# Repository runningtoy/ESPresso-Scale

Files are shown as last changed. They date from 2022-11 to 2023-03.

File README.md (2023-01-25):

 **ESPresso Scale**  
Fully open source (s/w & h/w) scale project.

**Fork of the great project of jousis9** [https://github.com/jousis9/ESPresso-Scale]  
Main work is done by him! Thanks

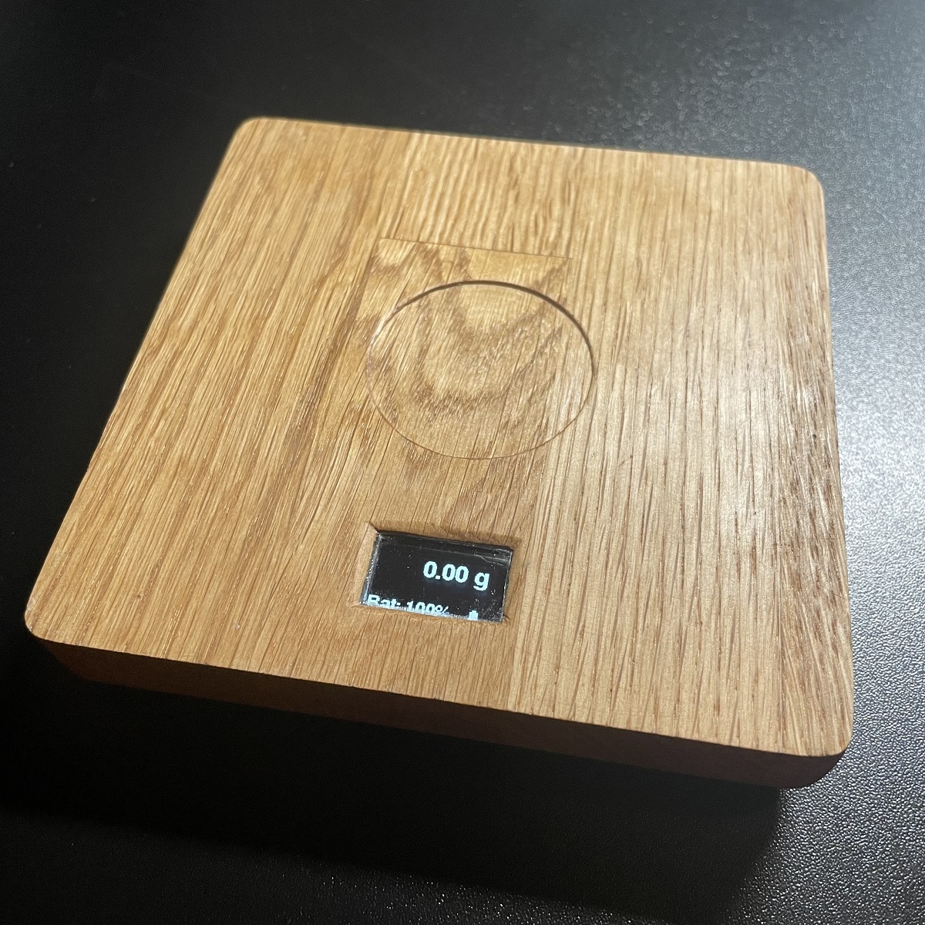
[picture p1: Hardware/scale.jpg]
Scale
  

**Features**
- Open source firmware, software and hardware
- ESP32 (wroom module) MCU
- ADS1232 24-bit ADC from TI
- Lipo and USB powered (I connected a wireless charging pad)
- 10SPS and 80SPS sampling speed with various options regarding filtering/smoothing
- Auto calibration function (selectable weight)
- Touch buttons , using ESP32 pins or external touch module (TTP223).
- 3d printed case (fusion360 files provided)
- Auto power off and consumes no power when "sleep" to extend battery life
- enable WiFi on demand (press both buttons during startup ) -> ```credentials.h```
- OTA support (if WiFi enabled) -> ```http://SCALEIP/update```
- UDP Logging (if WiFi enabled) to ```UDP_SERVER_IP```

**What is provided ?**
- [PCB assembly guide](./Hardware/Documents)
- [Schematics (PDF)](./Hardware/Schematics)
- [PCB easyEDA project export](./Hardware/easyEDA)
- [Fusion 360 project file for the cases](./Hardware/case)
- [Bill of materials (BOM)](./Hardware/Documents) *wip*
- [Firmware (Platform.io IDE project)](./Software/Firmware)

**Documentation**  
*UDP LOGGING Bash*  
Command for UDP Logging  
```bash
nc -u -l -p 44444
```  

**Load Cell**  
- [x] [Mavin NA1](https://www.mavin.cn/na1-oiml-c3-approved-load-cell-high-accuracy-single-point-sensor_p15.html) and 
- [x] [Mavin MV-NA27-2KG](https://www.mavin.cn/kitchen-scale-load-cell-low-capacity-weight-sensor-na27_p28.html)
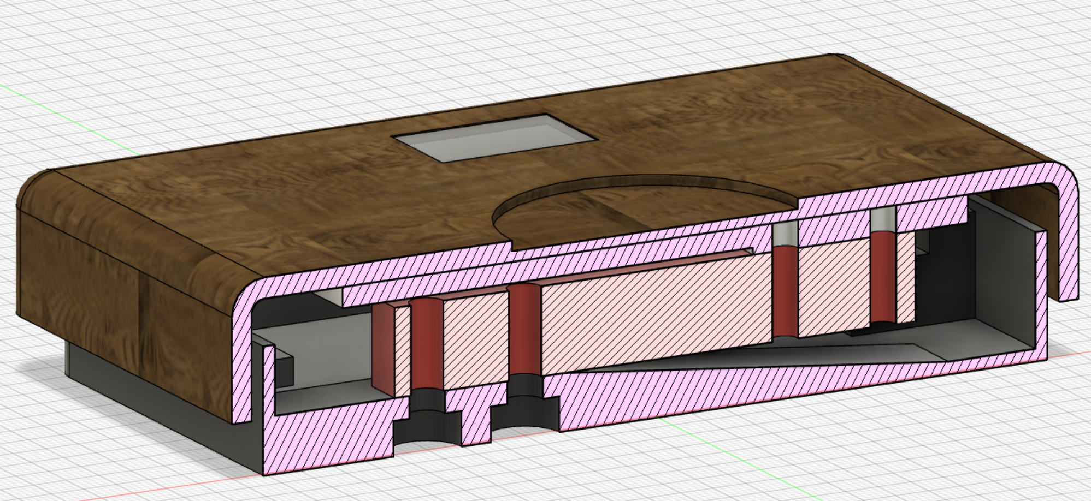
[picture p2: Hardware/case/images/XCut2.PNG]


**known Pitfall**  
[Repeatability](https://github.com/jousis9/ESPresso-Scale/issues/2#issue-1459375448)  
To avoid it I used an aluminum beam as a carrier and glued the top part of the case on the beam  and one at the bottom.
<p>
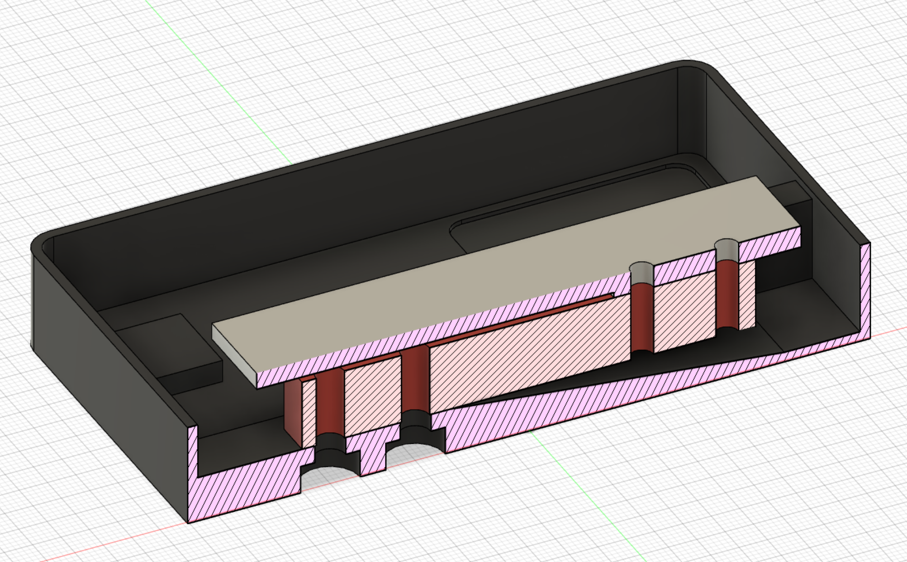
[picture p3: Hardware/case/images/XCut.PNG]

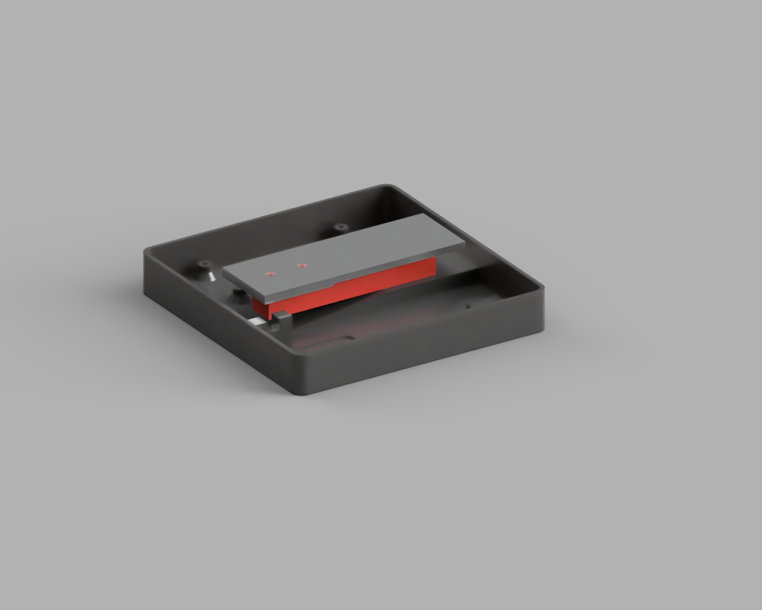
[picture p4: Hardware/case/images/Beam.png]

  
[Case and mounting]()  
due to sensibility of the scale use the most flexible cables and smallest possible diamater. Stiff cables can lead to extra force on the load cell which makes it useless. I used [AWG30 silicon cables](https://www.amazon.de/Fermerry-Litzendraht-verzinnte-Kupferdrahtspule-Elektrokabel-Kit/dp/B09BFQMWL4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)

**Consider contributing**  

**License**  
<!-- ![OSHW Certification](Hardware/OSHW_mark_GR000002_medium.png)   -->
Software under [GPL v3](https://gitlab.com/jousis/espresso-scale/blob/master/LICENSE)  
Hardware under [CERN Open Hardware Licence v1.2](https://gitlab.com/jousis/espresso-scale/blob/master/hw-LICENSE)  
Documentation under [CC BY-SA license 2.0](https://creativecommons.org/licenses/by-sa/2.0/)

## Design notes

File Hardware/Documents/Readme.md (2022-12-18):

# ESP^2^resso Scale PRO

##PCB Assembly Guide

(based on & all credits to [jousis9 Documents](https://github.com/jousis9/ESPresso-Scale/tree/master/Hardware/Documents))

**WIP**

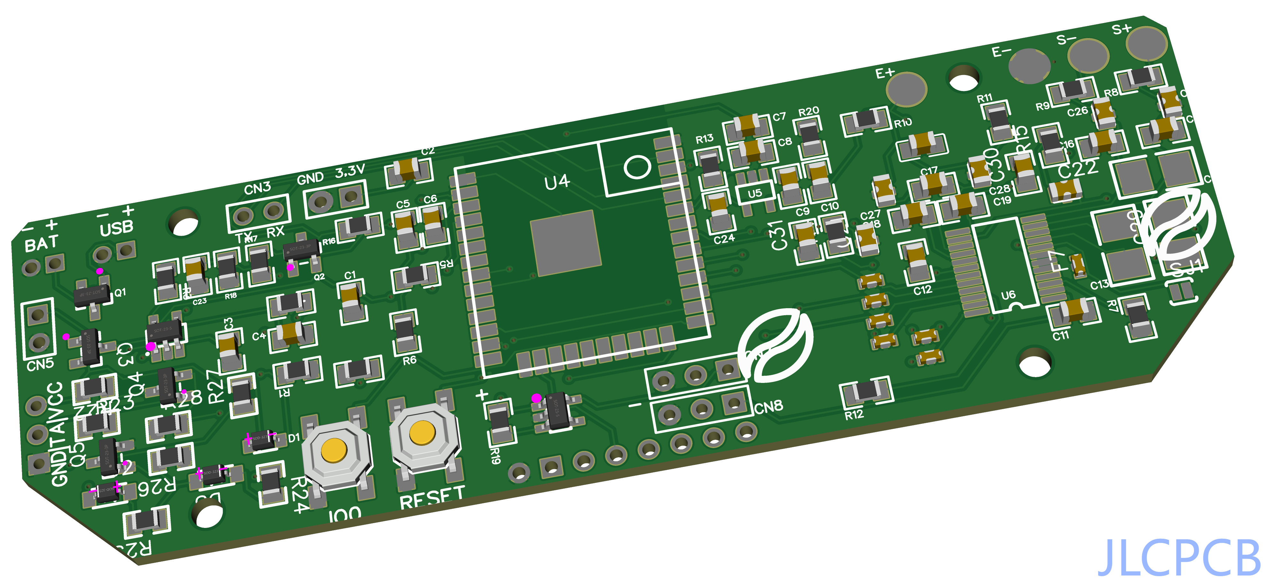
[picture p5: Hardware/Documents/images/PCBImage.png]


With a little care, you can easily hand solder all the components. No
need for hot air.

If you want to minimize the cost, all components except the ADC can be
replaced with cheaper alternatives. Try to avoid very cheap components
in the analog section (RC filtering) or you might lose some
accuracy/stability.

**Why "espresso" scale?**
High resolution, high refresh rate needed during an espresso extraction.
Apart from that, it is a normal scale.

**Why "PRO"?**
You can use any SPI (or I2C) screen (even TFT with backlight pin),
slightly better RC filtering, speed/gain control of the ADC from the
software, better separation of analog/digital tracks, power on/off of
the second LDO, use of second ADC Input

**JLPCB**
I orderd my PCBs preassambled at JLPCB. To reduce manual work I moved most parts on TOP Layer 
All files are [here](../easyEDA/) 10pcs ~90€ (excl. ESP32 and ADS1232)

##Top Layer

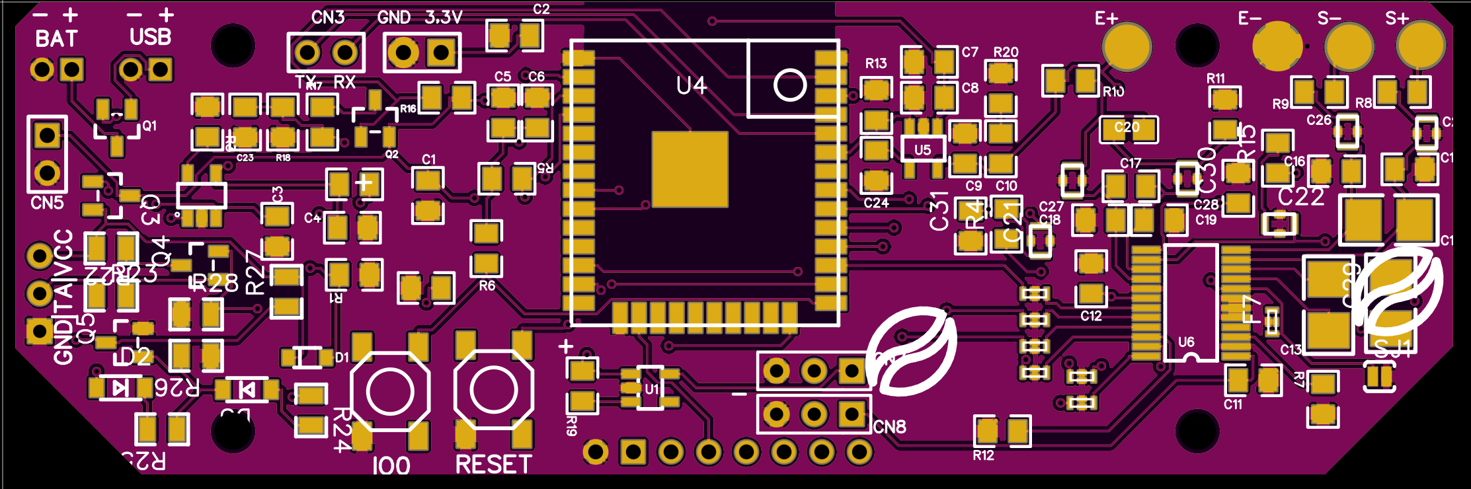
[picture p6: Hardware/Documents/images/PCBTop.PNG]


##Section 1 -- USB / Battery Input & charging

[Battery charging circuit design: Sparkfun ESP32 Thing](https://cdn.sparkfun.com/assets/learn_tutorials/5/0/7/esp32-thing-schematic.pdf)

If you don't care about battery / battery charging you can connect DC+5V
to CN5 and do not solder any of the parts shown above.

###Power Down circute
[Latching Power Circuit: randomnerdtutorials.com](https://randomnerdtutorials.com/power-saving-latching-circuit/)
If you do not want to use it. Connect Pin3 & Pin2 of P1 to disable. If you use it don't forget to set PWR_ON on to ```high``` on boot and ```low``` when shut down

##Section 2 -- LDO & MCU

###LDO (U1)

You can use any LDO pin-compatible with TLV75533PDBVR (SOT-23-5). You
don't need one with enable pin but if it has one, check its datasheet
and:

-   If it needs logic high for enable, solder R19 (100K). R19 goes to
    vin (C1).

-   If it needs logic low solder a jumper cable from R19 right pad to
    GND of CN5.

CN5 is optional header, you can use it to give power to the LDO without
having to connect the Section 1 part. Very handy for testing.

###MCU (U4)

You can use any esp32 wroom with the same footprint (ESP32, ESP32D,
ESP32U).

##Programming

The only way to program your MCU for the 1^st^ time is through the
serial connector on the bottom. There is no ftdi chip on the PCB.
Afterwards, if you wish, you can setup an OTA method.

##Touch Input

use external touch module (TTP223)

##Section 3 -- ADC / Load Cell

###Analog Voltage LDO

U5 is the local LDO for the excitation voltage of the load cell (and
reference voltage). Use high quality components on everything related to
the analog circuit.

###R20

Is there to add some resistance to C10 if you want to use MLCC and your
LDO works better with some ESR (most). If you don't want to use any R
there (not even 0R?), solder bridge both pads.\
**Warning: C20 is not grounded. It goes to ground through R20.**

###C24

Completely optional. Only if your LDO had a need/option for Cnr
capacitor to reduce its output noise. Check datasheet for correct value.

###Comments on the analog LDO

You don't have to use any of them but since this is a very crucial part
of the scale, I like to share my thoughts and experiments.

Disclaimer: I know there is a pattern in my project with a special brand
(TI) but I am not in any way affiliated to them, everything was paid
using my own money. I cannot deny though that I really like the quality
and specs of their components.

###Option 1 -- OK for battery use (BOM)

TPS7A0533PDBVR

200mA **3.3V** with 210mV dropout and **1uA Iq while working (0.1A on
shutdown)**. Good all around. You can use this LDO only with 5V input
(max Input 5.5V). Place 0R on R20 or solder bridge the pads, leave C24
unpopulated.

I used this LDO with most of my tests, works well but it is nothing
extraordinary. If your main use is battery, excitation voltage cannot go
above 3.3V (maybe slightly) so 3.3V regulator is all we need.

###Option 2 -- OK for battery use

TLV75533PDBVR

500mA **3.3V** with 210mV dropout and **25uA Iq while working (0.1A on
shutdown)**. Good all around. You can use this LDO only with 5V input
(max Input 5.5V). Place 0R on R20 or solder bridge the pads, leave C24
unpopulated.

I used this LDO with most of my tests, works well but it is nothing
extraordinary. If your main use is battery, excitation voltage cannot go
above 3.3V (maybe slightly) so 3.3V regulator is all we need.

[Note: you can use this LDO for both analog and digital, reducing the
parts you will need to buy.]{.ul}

###Option 3 -- OK for mixed use (DC / Battery)

TPS76950DBVR

100mA **5V** with 70mV dropout, **17uA while working (1uA on
shutdown)**. Its max input V is 10V so if you provide 7V+ input you will
have 5V excitation voltage for our load cell. The same LDO will work
fine on battery but if you don't intend to provide DC input on the
scale, prefer the TPS7A for its low Iq. Place 0R on R20 or solder bridge
the pads, leave C24 unpopulated.

Advantages:

-   Up to 5V excitation voltage (with 10V\>Vin\>7V) for increased
    accuracy

-   Very low dropout voltage

Disadvantages:

-   Works fine on battery due to its relatively low Iq but not as well
    as option1

###Option 4 -- Low noise -- mixed use

TPS73643DBVR (4.3V) or TPS73633DBVR (3.3V)

400mA with 75mV dropout and **500uA** **ground current while working,
0.02uA on shutdown**. With C24 (0.01uF) this LDO has very low noise on
output. The drawback is its very high ground current while working. For
short periods on, large periods off (espresso), it is a viable option.
Also note its impressive shutdown current (0.02uA). TPS73643DBVR is the
optimal solution here for mixed use (battery/5V DC). You will get 4.3V
excitation voltage while on DC for increased accuracy. Place 0R on R20
or solder bridge the pads.

Warning: check firmware options, this LDO needs LOW for enable and HIGH
for disable.

Advantages:

-   Up to 4.3V excitation voltage (max Vin 5.5V)

-   Very low noise if you populate C24 (0.01uF)

-   Very low shutdown current

-   Very low dropout voltage

-   3.3V can be used as a main LDO as well, reducing the parts you need
    to buy (not recommended)

Disadvantages:

-   Very high ground current while working.\
    Not recommended for prolonged use while on battery. Decrease
    light/deep sleep timeout on firmware (those two options shut down
    the ADC LDO).\
    Not recommended for use as main LDO (0.5mA consumption is a lot)

-   Very expensive, low availability

###Option 5 -- DC input only (\<16V)

LP2985-50DBVR (5V) -- not tested yet

150mA with 280mV dropout and 850uA **ground current (0.01uA on
shutdown).** Since we don't mind about dropout and ground current, this
LDO is a good option because of its low noise and stable operation with
MLCC. Place 0R on R20 and 0.01uF capacitor on C24.

Warning: proposed main LDO cannot accept \>5.5V. You will need to change
it as well (see SPX3819M5-L-3-3)

Advantages:

-   Up to 5V excitation voltage for increased accuracy

-   Wide DC input voltage (\<16V)

-   Very low noise if you populate C24 (0.01uF)

-   Very low shutdown current

-   Good price (especially in quantity), good availability.

Disadvantages:

-   Very high ground current while working

##ADC

Compared to the HX711 used in almost all the cheap (and not) designs,
ADS1232 from TI is very accurate and stable. Although much more
expensive, for this type of scale it is an expense you will have to
make. Even when heating it up it could manage 0.1g accuracy (has
internal temp sensor). Kudos to TI for their awesome documentation and
white papers. (notice: This project is in no way affiliated with TI)

Digital +3.3V comes from the main LDO, analog +3.3V from the local LDO.
There is only one ground for both signals (analog/digital) but I tried
to avoid any digital signal return path through the analog part of the
ADC. Unfortunately, due to the size constraints and the large number of
tracks needed for the LED segment controller, digital and analog tracks
are relatively close together. That said, I tested the same design with
separate analog ground (join under the ADC) and couldn't find measurable
difference.

**Notice: ADS1232 does not communicate using standard SPI. Please see my
(or any other) library.**

##RC filtering

Finally, I settled with the reference design and parts. The only
exception is that I replaced the small 100pF PPS (ECH-U1C101GX5) with
NP0 (GRM2165C1H101FA01D) caps to lower the cost a little.

##Why those tiny feed throughs?

I cannot measure/see any difference with/without them, but TI knows best
(they have them on the reference design). Run a jumper cable across if
you don't have them or even edit the pcb and remove them completely (if
you can't ask me -- I can make a new revision).

##Bottom Layer

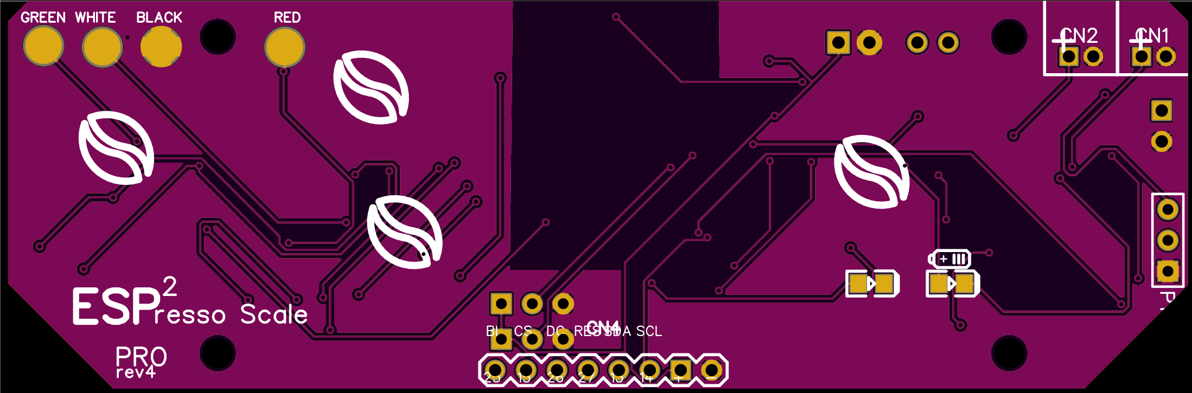
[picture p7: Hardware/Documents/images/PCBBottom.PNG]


- Battery warning (works also while on deep sleep) & LEDs
- Status LED if powered up

U3 is a simple voltage supervisor circuit that will light CHRG LED (LED1) is enabled when battery is
charging.

INDICATOR (LED3) is connected to mcu IO and you can use it in any way
you like.

##Connectors

- **CN4** : Display
    From left to right as you see on the picture above:
    5.  SDA -- IO13 (HSPI MOSI)
    6.  SCL -- IO14 (HSPI SCK)
    7.  VCC
    8.  GND
- **CN3**  : Serial
- **CN9**  : 3.3V input
- **CN5**  : 5V Input (without battery & PowerLatchCircute)
- **CN7&8**  : Buttons
- **CN1**  : Battery
- **CN2**  : 5V USB/Wireless Charging Pad 
- **P1**  : Power Letch Trigger
- **SJ1**  : disable seconde ADC input 
- **Green, White, Red & Black (Top)**  : ADC 1 input 
- **Green, White, Red & Black (Bottom)**  : ADC 2 input

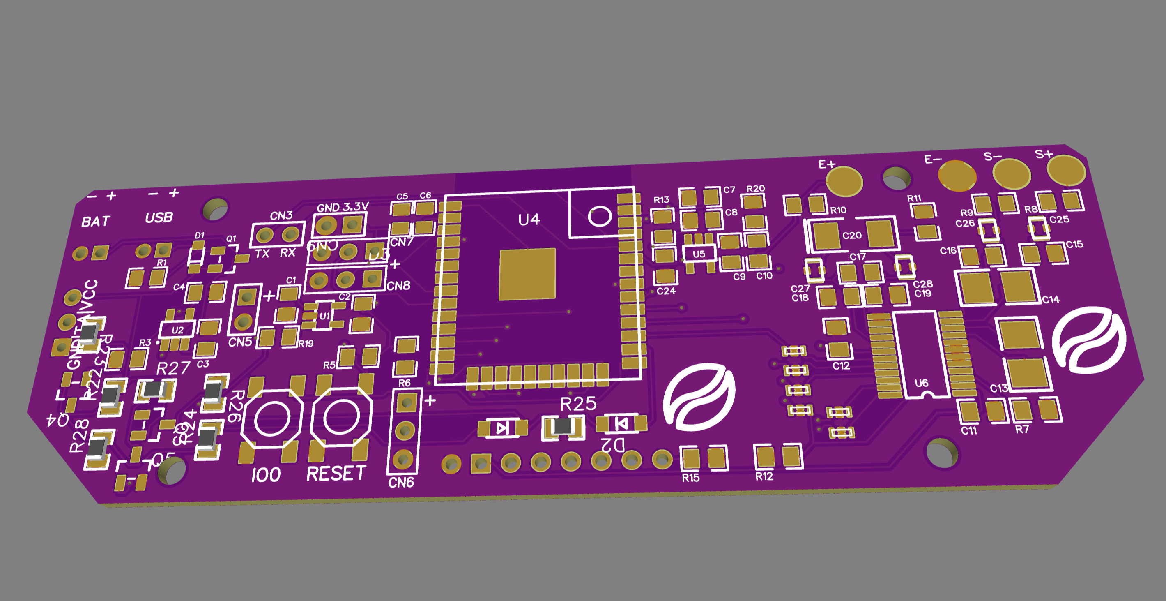
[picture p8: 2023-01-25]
Hardware/easyEDA/PCBImage.png

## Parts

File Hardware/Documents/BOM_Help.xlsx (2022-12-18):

ID | Name | Designator | Footprint | quick info | Quantity | Try Cheaper ? | Manufacturer Part | Manufacturer | Supplier | cost (euro for 1 unit) | Supplier URL
1 | 4.7u | C2,C3,C4,C10 | 0805 | 4.7uF, 16V | 4 | YES | GRM21BR71C475KE51L | murata | mouser | 0.84 | https://gr.mouser.com/ProductDetail/GRM21BR71C475KE51L/
2 | 1u | C1,C7 | 0805 | 1uF, 16V | 2 | YES | GRM21BR71C105JA01K | murata | mouser | 0.314 | https://gr.mouser.com/ProductDetail/GRM21BR71C105JA01K/
3 | 10u | C5 | 0805 | 10uF, 16V | 1 | YES | GRM21BC81C106KE15K | murata | mouser | 0.166 | https://gr.mouser.com/ProductDetail/GRM21BC81C106KE15K/
4 | 0.1u | C6,C8,C23 | 0805 | 0.1uF, 16V | 3 | YES | CC0805JRX7R7BB104 | yageo | mouser | 0.471 | https://gr.mouser.com/ProductDetail/CC0805JRX7R7BB104/
5 | 10n | C9 | 0805 | 0.01uF (10nF), 50V | 1 | YES | 885012207092 | Wurth | mouser | 0.08 | https://gr.mouser.com/ProductDetail/710-885012207092/
6 | 10n | C24 | 0805 | Optional 0.01uF for low noise, read assembly guide | 1 | YES | 885012207092 | Wurth | mouser | 0.08 | https://gr.mouser.com/ProductDetail/710-885012207092/
7 | 2.2u | C17 | 0805 | 2.2uF, 16V | 1 | Might lose accuracy/stability | GCM21BR71A225JA37L | murata | mouser | 0.367 | https://gr.mouser.com/ProductDetail/GCM21BR71A225JA37L/
8 | 2.2u | C11,C12 | 0805 | 2.2uF, 16V | 2 | YES | VJ0805G225KXQTW1BC | VISHAY | mouser | 0.314 | https://gr.mouser.com/ProductDetail/77-VJ0805G225KXQTBC/
9 | 0.1u PPS ECH-U1C104GX5 | C13,C14 | 1210 | 0.1uF PPS, 16V | 2 | Might lose accuracy/stability | ECH-U1C104GX5 | Panasonic | mouser | 1.484 | https://gr.mouser.com/ProductDetail/667-ECH-U1C104GX5/
10 | 100p NP0 | C15,C16,C18,C19 | 0805 | 100pF, NP0, 50V, 1% | 4 | Might lose accuracy/stability | GRM2165C1H101FA01D | Murata | mouser | 0.664 | https://gr.mouser.com/ProductDetail/GRM2165C1H101FA01D/
11 | 100uF (T) | C20 | Case C | 100uF, Tantalum, 10V | 1 | YES | TP3C107K010D0900AS | VISHAY | mouser | 0.568 | https://gr.mouser.com/ProductDetail/TP3C107K010D0900AS/
12 | 1u feed through | C25,C26,C27,C28 | 0805 | 1uF Feed through | 4 | Might lose accuracy/stability | NFM21PC105B1C3D | Murata | mouser | 0.84 | https://gr.mouser.com/ProductDetail/NFM21PC105B1C3D/
13 | DF3A-2P-2DS | CN1,CN2 | DF3A-2P-2DS | power/battery connector | 2 | YES | DF3A-2P-2DS | Hirose | mouser | 0.175 | https://gr.mouser.com/ProductDetail/DF3A-2P-2DS/
14 | 2.54_HEADER_2P | CN3,CN5 | 2P_2.54 | serial/5V bypass power | 1
15 | Header-M2.54_1x8 | CN4 | 210S-1X8P | oled/tft SPI connector | 1
16 | Header1x3_2.54 | CN6,CN7,CN8 |  | external buttons | 3
17 | BAT20JFILM | D1 | SOD-323 |  | 1 | YES | BAT20JFILM | STMicroelectronics | mouser | 0.332 | https://gr.mouser.com/ProductDetail/BAT20JFILM/
18 | 100pF feed through | F1,F2,F3,F4,F5,F6 | 0603 | feed through caps for the digital signal lines of the ADC. Works fine without them. | 6 | Yes,you can also omit them but be carefull not to short with G when using bypass cable :) | NFM18CC101R1C3D | MuRata | mouser | 1.572 | https://gr.mouser.com/ProductDetail/81-NFM18CC101R1C3D/
19 | CHRG | LED1 | 0805 | 2V, 20mA | 1 | YES | 150080YS75000 | Wurth | mouser | 0.16 | https://gr.mouser.com/ProductDetail/150080YS75000/
20 | LOW BAT | LED2 | 0805 | 1.75V , for low battery warning | 1 | YES | APTD2012LSURCK | Kingbright | mouser | 0.402 | https://gr.mouser.com/ProductDetail/604-APTD2012LSURCK/
21 | INDICATOR | LED3 | 0805 | 2V, 20mA | 1 | Yes, you can also omit it | 150080BS75000 | Wurth | mouser | 0.16 | https://gr.mouser.com/ProductDetail/150080BS75000/
22 | SQ2303ES-T1_GE3 | Q1,Q2 | SOT-23(SOT-23-3) |  | 2 | YES | SQ2303ES-T1_GE3 | VISHAY | mouser | 0.874 | https://gr.mouser.com/ProductDetail/SQ2303ES-T1_GE3/
23 | 10k | R1,R5,R6,R17,R18 | 0805 | 10K, 1% | 5 | YES | ERJ-6ENF1002V | Panasonic | mouser | 0.435 | https://gr.mouser.com/ProductDetail/ERJ-6ENF1002V/
24 | 1k | R2,R15 | 0805 | 1K, 1% | 1 | YES | ERJ-6ENF1001V | Panasonic | mouser | 0.087 | https://gr.mouser.com/ProductDetail/ERJ-6ENF1001V/
25 | 2k | R3 | 0805 | 2K, 1% | 1 | YES | ERJ-6ENF2001V | Panasonic | mouser | 0.087 | https://gr.mouser.com/ProductDetail/667-ERJ-6ENF2001V/
26 | 330R | R4,R14 | 0805 | 330R, 1% | 1 | YES | CRCW0805330RFKEAC | VISHAY | mouser | 0.087 | https://gr.mouser.com/ProductDetail/71-CRCW0805330RFKEAC/
27 | 47K | R7,R12 | 0805 | 47K,1% | 2 | YES | ERJ-6ENF4702V | Panasonic | mouser | 0.49 | https://www.mouser.com/ProductDetail/667-ERJ-6ENF4702V/
28 | 100R | R10,R11 | 0805 | 100R, 1% | 4 | YES | ERJ-6ENF1000V | Panasonic | mouser | 0.348 | https://gr.mouser.com/ProductDetail/ERJ-6ENF1000V/
29 | 0R | R8,R9 | 0805 | 0R, 1% | 2 | YES | RC0805FR-130RL | Yageo | mouser | 0.192 | https://gr.mouser.com/ProductDetail/603-RC0805FR-130RL/
30 | 100K | R13,R16,R19 | 0805 | 100K, 1% | 3 | YES | ERJ-6ENF1003V | Panasonic | mouser | 0.261 | https://gr.mouser.com/ProductDetail/667-ERJ-6ENF1003V/
31 | ???R | R20 | 0805 | optional, to add some R to the output of the LDO. More info on assembly guide.
32 | RESET | SW1 |  |  | 1 | YES | PTS525SM15SMTR2LFS | C&K | mouser | 0.288 | https://gr.mouser.com/ProductDetail/611-PTS525SM15SMTR2/
33 | IO0 | SW2 |  |  | 1 | YES | PTS525SM15SMTR2LFS | C&K | mouser | 0.288 | https://gr.mouser.com/ProductDetail/611-PTS525SM15SMTR2/
34 | TLV75533PDBVR | U1 | SOT-23-5 | main LDO (500mA) | 1 | YES | TLV75533PDBVR | TI | mouser | 0.541 | https://gr.mouser.com/ProductDetail/595-TLV75533PDBVR/
35 | MCP73831T-2ATI/OT | U2 | SOT-23-5 |  | 1 | YES | MCP73831T-2ATI/OT | MICROCHIP | mouser | 0.507 | https://gr.mouser.com/ProductDetail/MCP73831T-2ATI-OT/
36 | TLV809K33DBVR | U3 | SOT-23-3 | 2.93V, Active-low,Push-pull | 1 | Yes, it is only for low battery warning... you can completely remove it, along with LED2 and R12 | TLV809K33DBVR | TI | mouser | 0.576 | https://gr.mouser.com/ProductDetail/595-TLV809K33DBVR
37 | ESP32_ESP_WROOM_32U | U4 | ESP32_ESP_WROOM_32U |  | 1 | Yes, use any other with same footprint (ex. 32D with antenna) | ESP32-WROOM-32U | Espressif | mouser | 3.49 | https://gr.mouser.com/ProductDetail/ESP32-WROOM-32U/
38 | TPS7A0533PDBVR | U5 | SOT-23-5 | ADC LDO (200mA) | 1 | Yes, use any other, but of high quality. Try one with 4.7-5Voutput | TPS7A0533PDBVR | TI | mouser | 0.515 | https://gr.mouser.com/ProductDetail/595-TPS7A0533PDBVR/
39 | ADS1232IPWR | U6 | TSSOP-24 |  | 1 | r u kidding me ? | ADS1232IPWR | TI | mouser | 7.13 | https://gr.mouser.com/ProductDetail/ADS1232IPWR/
40 | OLED/TFT with SPI interface (can also use any other interface using the same pins). Be carefull with VCC/GND pins. Might be the other way around. |  |  |  | 1 | YES |  |  | aliexpress | 3 | https://www.aliexpress.com/item/IPS-0-96-inch-7P-SPI-HD-65K-Full-Color-LCD-Module-ST7735-Drive-IC-80/32859445140.html
41 | lipo battery |  |  | 1600mAh | 1 | YES |  |  | grobotronics | 12 | https://grobotronics.com/polymer-lithium-ion-battery-3.7v-1600mah.html
42 | antenna |  |  | Optional, will work without in close range | 1 | YES | ANTX100P011B24003 | Yageo | mouser |  | https://gr.mouser.com/ProductDetail/603-ANTX100P011B2400/
43 | load cell |  |  | 200g-500g high precision for espresso, 500g++ for other | 1 | YES |  |  | aliexpress | 4 | https://www.aliexpress.com/item/200g-small-range-high-precision-weighing-sensor-load-cell-weight-sensor/32746278566.html
 |  |  |  |  |  |  |  | Cost (w/o VAT): |  | 40.185

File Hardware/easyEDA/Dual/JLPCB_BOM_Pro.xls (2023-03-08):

Comment | Designator | Footprint | JLCPCB Part # | wrongPartsFirstOrder?
RESET | SW2,SW1,SW2,SW1 | KEY-5.2X5.2X1.5 | C318884
1u | C1 | 0805 | C28323
2.2u | C11,C12 | 0805 | C49217
100k | R13,R16,R19,R27,R26 | 0805 | C149504
1R | R20 | 0805 | C25271
B5819W SL | D2,D3 | SOD-123F | C8598
4.7u | C10,C4,C3,C2 | 0805 | C1779
2k | R3 | 0805 | C17604
AO3413 | Q3,Q2,Q1 | SOT-23(SOT-23-3) | C86648
NFM21PC105B1C3D | C25,C26,C28,C21,C22,C27 | NFM21-0805-4PIN | C92518
10n | C9 | 0805 | C1710
47K | R7,R12 | 0805 | C17713
10k | R18,R17,R22,R5,R1,R6,R18,R17,R22,R5,R1,R6,R18,R17,R22,R5,R1,R6, R24 | 0805 | C17414
100R | R10,R11 | 0805 | C17408
220 | R25 | R0805 | C17557
100pNP0 | C19,C18 | 0805 | C167431
220k | R28 | R0805 | C17556
1k | R2,R23,R2,R23 | R0805 | C17513
10u | C5 | 0805 | C15850
2N3904 | Q4,Q5 | 2N3904SMD | C20526
1u | C23,C6,C23,C6,C8,C24,C7,C8,C24,C7,C8,C24,C7 | 0805 | C49678
MCP73831T-2ATI/OT | U2 | SOT-23-5 | C14879
TLV75533PDBVR | U1 | SOT23-5 | C404027
100pF | F1,F2,F6,F5,F7,F4,F3,F1,F2,F6,F5,F7,F4,F3 | SMD-L-1.6MMX0.8MM | C184122
0R | R8,R9,R15,R4 | 0805 | C17477
330R | R14 | 0805 | C17630
100pNP0 | C31,C30,C16,C15,C19,C18 | 0805 | C77059
2.2uF | C17 | 0805 | C77078
100uF(T) | C20 | C0805 | C521075
ADS1232IPWR | U6 | TSSOP-24 | C27919
BAT20JFILM | D1 | SOD-323 | C155590
LDO | U5 | SOT23-5 | C404027

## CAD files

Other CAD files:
Hardware/case/Fusion 360/ESPressoScale_Mavin_NA1.f3d
Hardware/case/Fusion 360/ESPressoScale_Mavin_NA27.f3d

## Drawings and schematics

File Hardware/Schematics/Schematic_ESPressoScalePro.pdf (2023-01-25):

IO0 25 IO4 26 IO16 27 IO17 28 IO5 29 IO18 30 IO19 31 NC 32 IO21 33 RXD0_IO3 34 TXD0_IO1 35 IO22 36 IO23 37 GND 38 GND 39

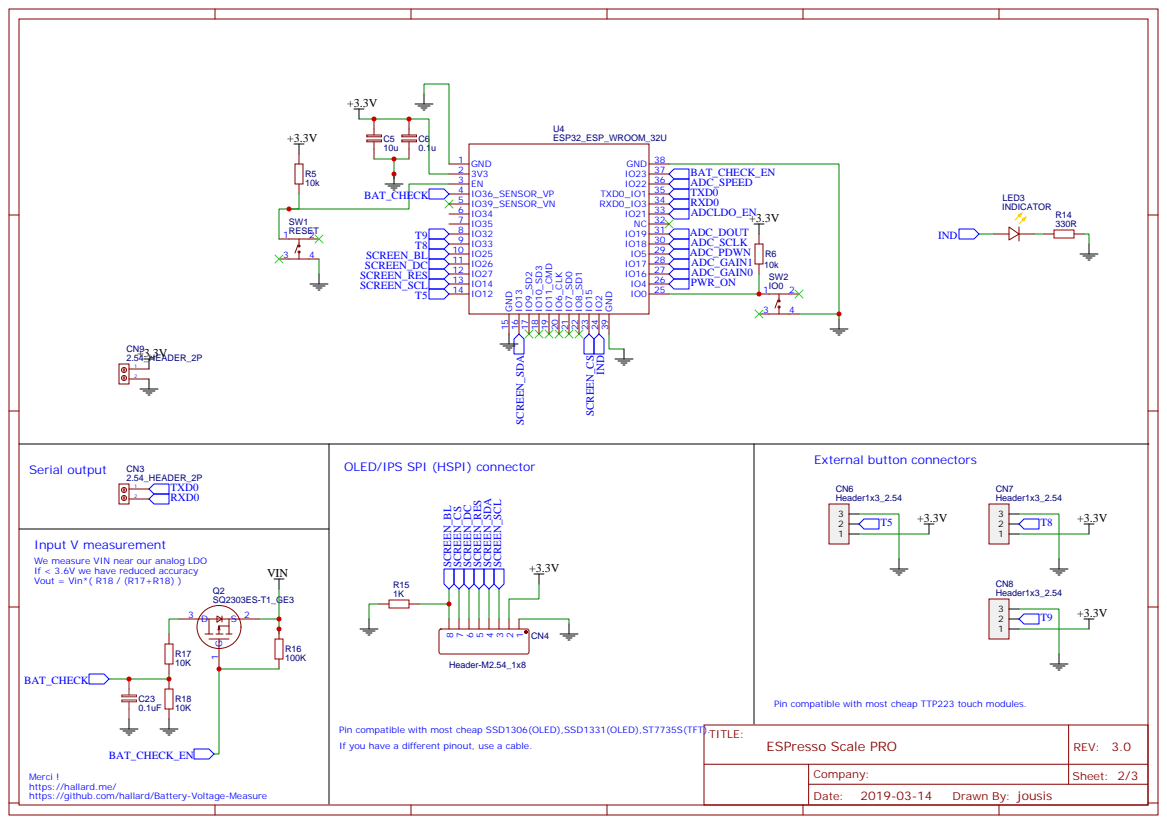
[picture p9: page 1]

OLED/IPS SPI (HSPI) connector

Input V measurement
We measure VIN near our analog LDO
If < 3.6V we have reduced accuracy
Vout = Vin*( R18 / (R17+R18) )

Pin compatible with most cheap TTP223 touch modules.

Pin compatible with most cheap SSD1306(OLED),SSD1331(OLED),ST7735S(TFT).
If you have a different pinout, use a cable.

Merci !
https://hallard.me/
https://github.com/hallard/Battery-Voltage-Measure

## Analog +3.3V LDO

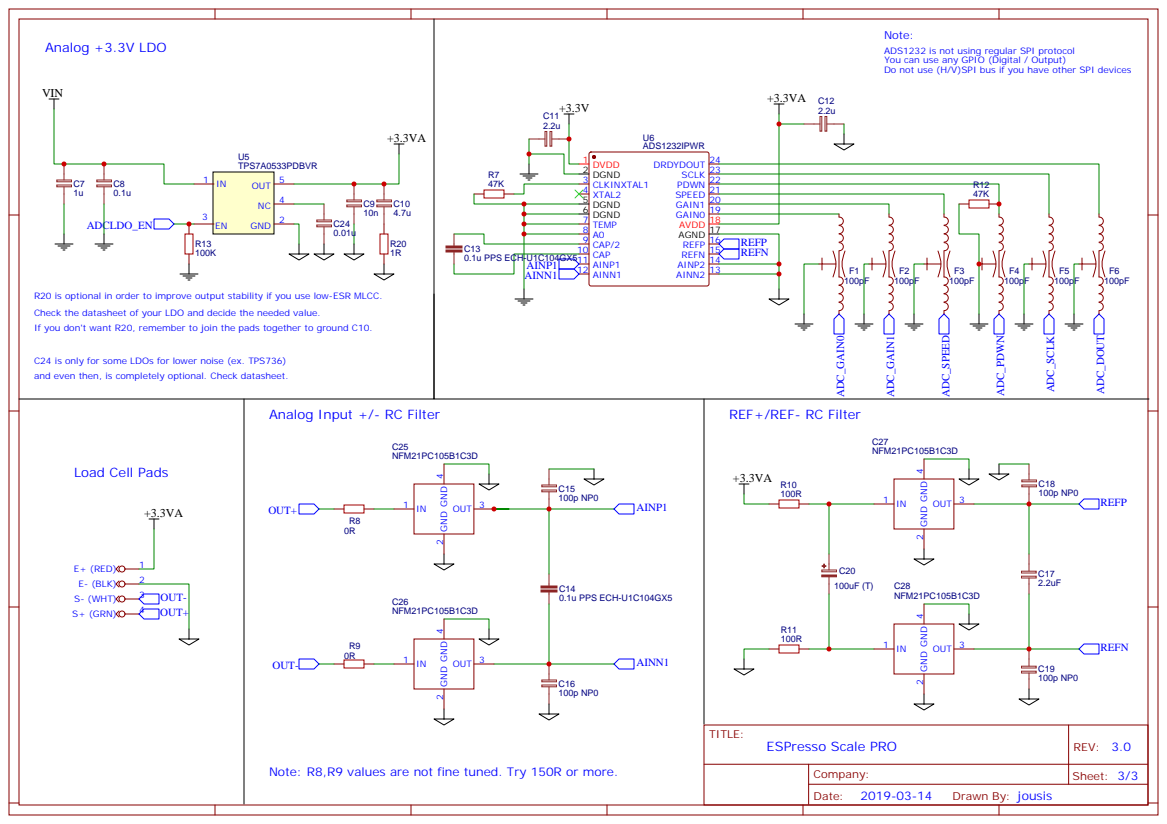
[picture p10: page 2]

Note:
ADS1232 is not using regular SPI protocol
You can use any GPIO (Digital / Output)
Do not use (H/V)SPI bus if you have other SPI devices

R20 is optional in order to improve output stability if you use low-ESR MLCC.
Check the datasheet of your LDO and decide the needed value.
If you don't want R20, remember to join the pads together to ground C10.

C24 is only for some LDOs for lower noise (ex. TPS736)
and even then, is completely optional. Check datasheet.

Note: R8,R9 values are not fine tuned. Try 150R or more.

Power input (USB/Lipo) | Li-Po Charging

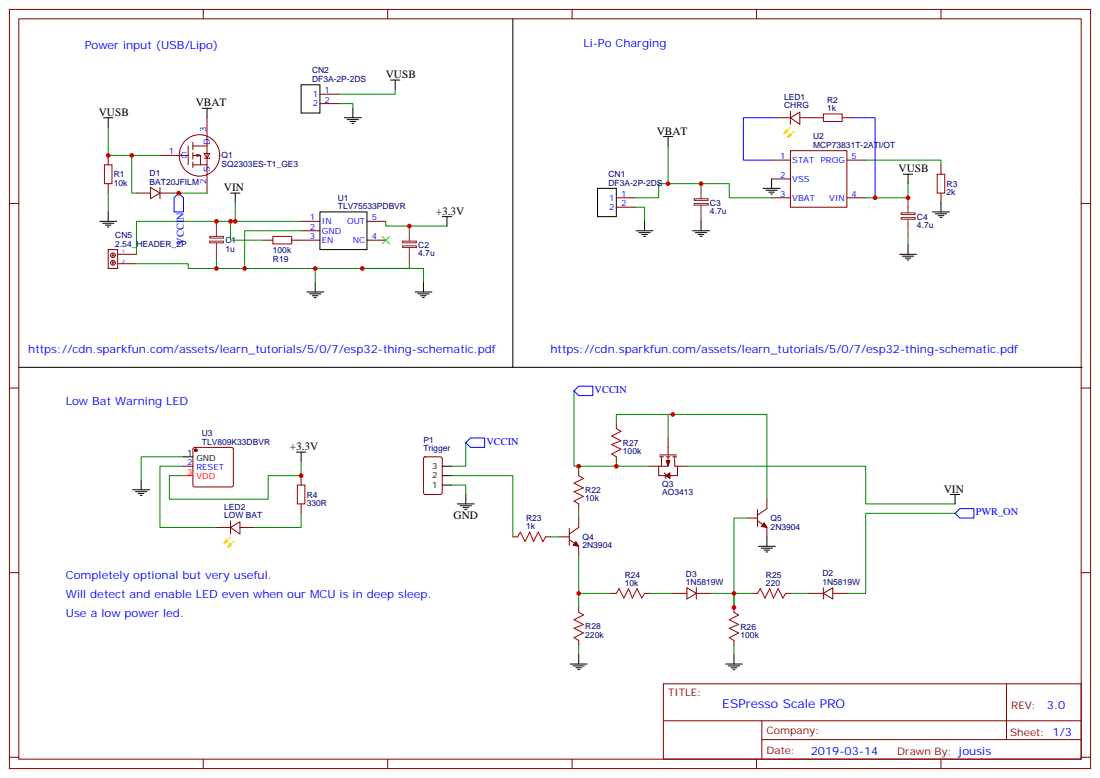
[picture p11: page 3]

Low Bat Warning LED

Completely optional but very useful.
Will detect and enable LED even when our MCU is in deep sleep.
Use a low power led.

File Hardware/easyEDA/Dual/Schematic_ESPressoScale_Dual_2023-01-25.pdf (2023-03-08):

Power input (USB/Lipo) | Li-Po Charging

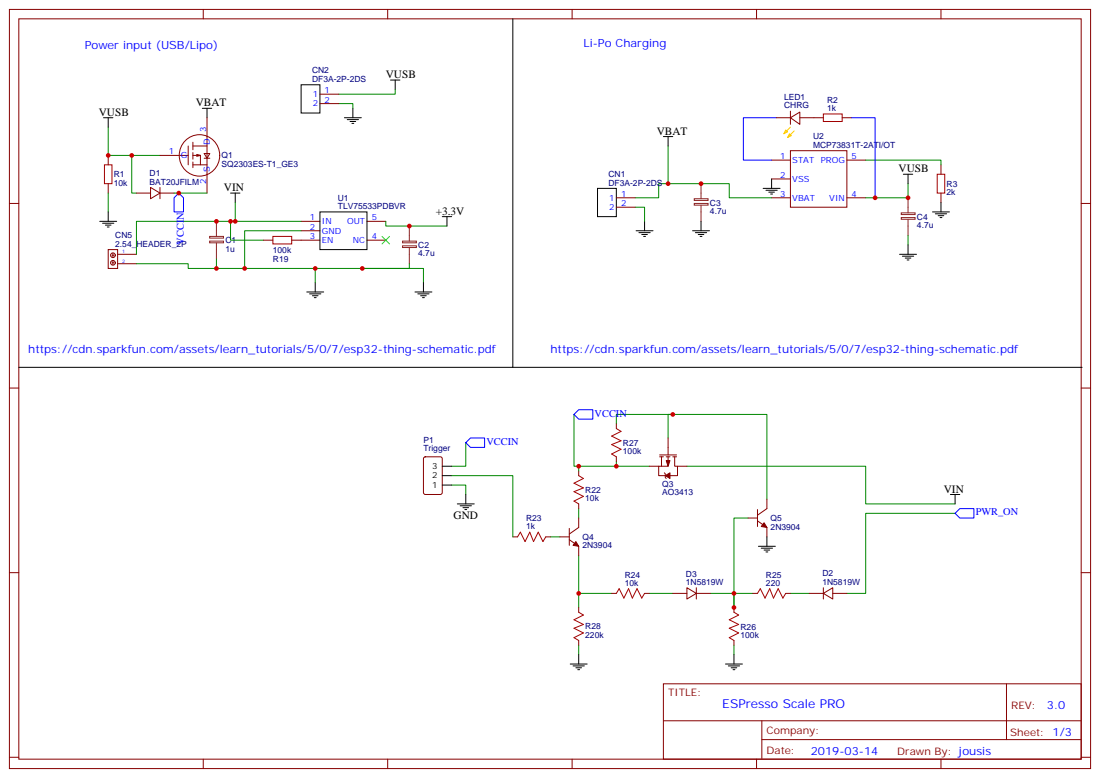
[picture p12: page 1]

## Analog +3.3V LDO

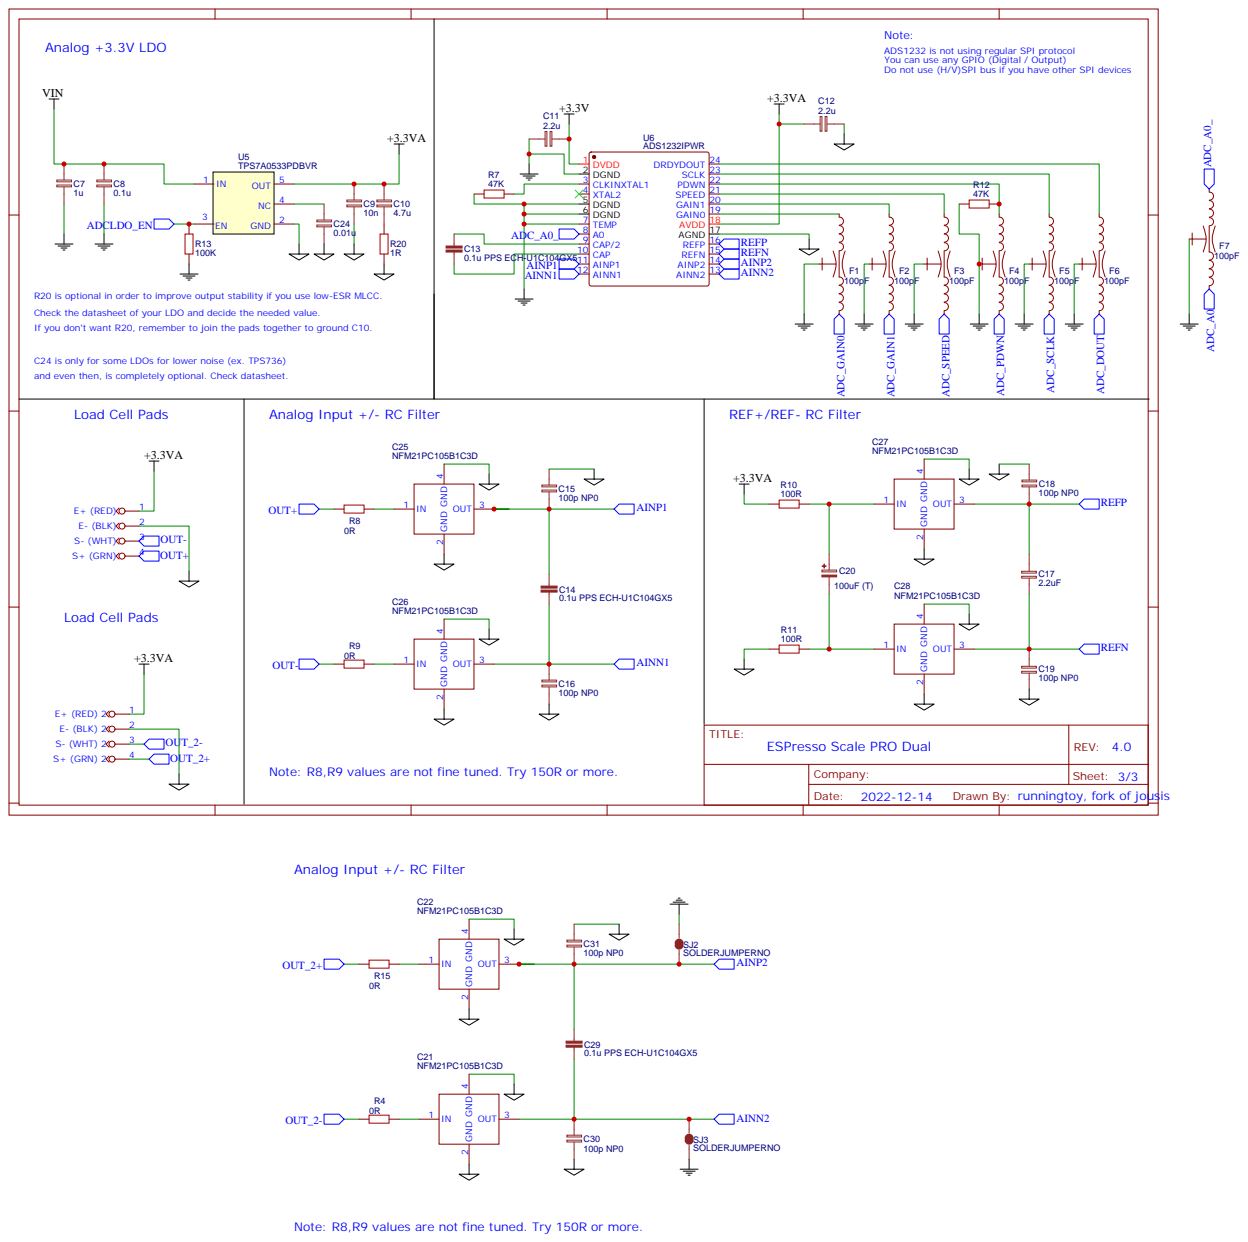
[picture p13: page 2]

Note:
ADS1232 is not using regular SPI protocol
You can use any GPIO (Digital / Output)
Do not use (H/V)SPI bus if you have other SPI devices

R20 is optional in order to improve output stability if you use low-ESR MLCC.
Check the datasheet of your LDO and decide the needed value.
If you don't want R20, remember to join the pads together to ground C10.

C24 is only for some LDOs for lower noise (ex. TPS736)
and even then, is completely optional. Check datasheet.

Note: R8,R9 values are not fine tuned. Try 150R or more.

Drawn By: runningtoy, fork of jousis

Analog Input +/- RC Filter

IO0 25 IO4 26 IO16 27 IO17 28 IO5 29 IO18 30 IO19 31 NC 32 IO21 33 RXD0_IO3 34 TXD0_IO1 35 IO22 36 IO23 37 GND 38 GND 39

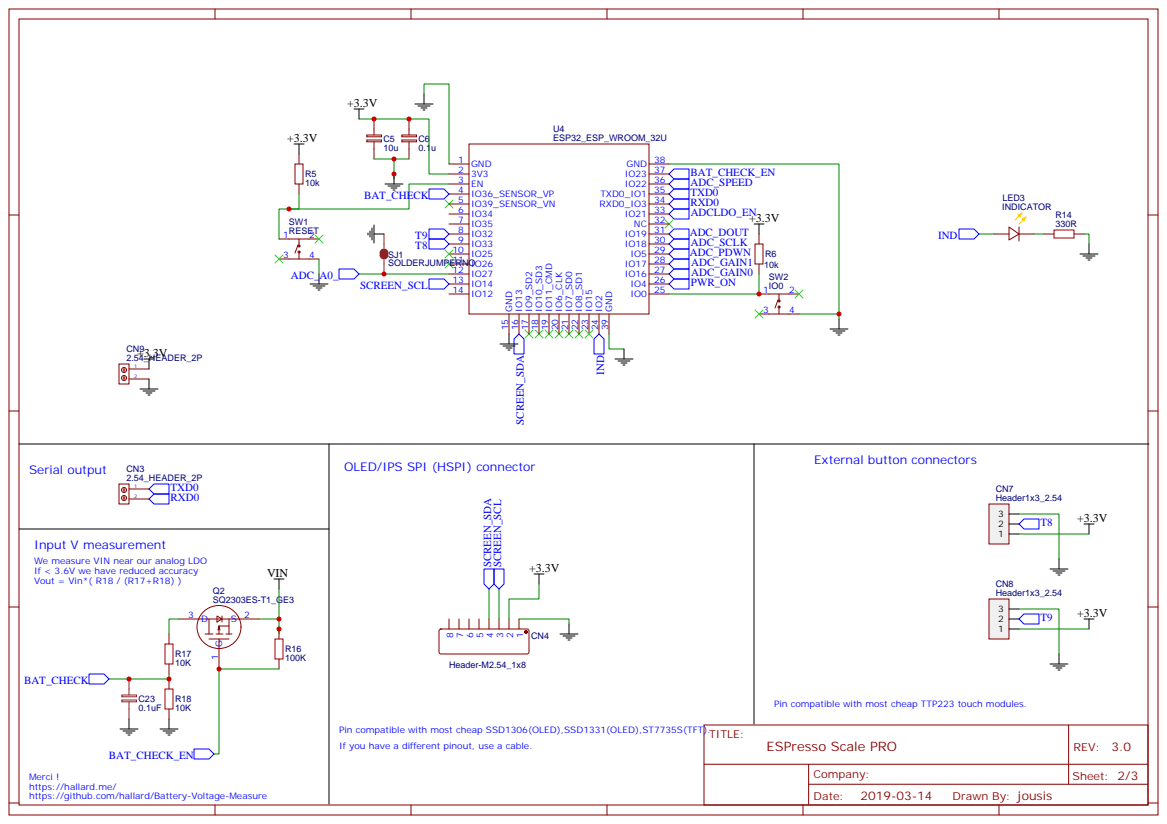
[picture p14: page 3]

OLED/IPS SPI (HSPI) connector

Input V measurement
We measure VIN near our analog LDO
If < 3.6V we have reduced accuracy
Vout = Vin*( R18 / (R17+R18) )

Pin compatible with most cheap TTP223 touch modules.

Pin compatible with most cheap SSD1306(OLED),SSD1331(OLED),ST7735S(TFT).
If you have a different pinout, use a cable.

Merci !
https://hallard.me/
https://github.com/hallard/Battery-Voltage-Measure

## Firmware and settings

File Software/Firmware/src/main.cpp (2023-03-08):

#include <Arduino.h>
#include "esp32Helper.h"
#include <Wire.h>
#include <Ticker.h>

#include <Adafruit_GFX.h>
#include "FreeSansBold9pt7b.h"
#include "FreeSansBold12pt7b.h"
#include <Adafruit_SSD1306.h>
#include "defines.h"
#include "scale.h"
#define ADS1232
#include "MONITORING.h"
#include "ArduinoNvs.h"
#include <AsyncTCP.h>
#include <ESPAsyncWebServer.h>
#include <AsyncElegantOTA.h>
#include "credentials.h"
#include "udp_logging.h"
#include "esp_log.h"
#include "esp_system.h"


AsyncWebServer server(80);
// const char* ssid = SSID;
// const char* password = PASSWORD;

SCALE scale = SCALE(ADC_PDWN_PIN, ADC_SCLK_PIN, ADC_DOUT_PIN, ADC_A0_PIN, ADC_SPEED_PIN, ADC_GAIN1_PIN, ADC_GAIN0_PIN, ADC_TEMP_PIN);
Adafruit_SSD1306 display(DISPLAY_WIDTH, DISPLAY_HEIGHT, &Wire, -1);
Ticker powerTicker;
Ticker displayTicker;
uint32_t powertimer = POWERDOWNTIMER;
MONITORING monitoring = MONITORING(23, 36); // enable mosfet pin = 23, vin on gpio36
bool timermode = false;
uint32_t start_timer = 0;
uint32_t calFactorULong = CALFACTORDEFAULT;
bool do_calibration = false;


#ifdef WIFIDEBUG
bool activeWifi = 1;
#else
bool activeWifi = 0;
#endif

uint32_t calibrationTimoutTime = 120000;
bool updateRunning = false;

double currentScaleValue=0;
double lastScaleValue=0;

#include "mybuttons.h"


const int wdtTimeout = WATCHDOGTIMEOUT*1000;  //time in ms to trigger the watchdog
hw_timer_t *wdtTimer = NULL;

void ARDUINO_ISR_ATTR resetModule() {
  ets_printf("reboot\n");
  digitalWrite(POWERLATCH, LOW);
  esp_restart();
}

void fct_setupWatchdog(){
  wdtTimer = timerBegin(0, 80, true);                  //timer 0, div 80
  timerAttachInterrupt(wdtTimer, &resetModule, true);  //attach callback
  timerAlarmWrite(wdtTimer, wdtTimeout * 1000, false); //set time in us
  timerAlarmEnable(wdtTimer);                   //enable interrupt
}

void fct_feedWatchdog(){
  timerWrite(wdtTimer, 0); //reset timer (feed watchdog)
  ESP_LOGV("fct_feedWatchdog", "feed Watchdog");
}



int count = 26;
void fct_bootLogo()
{
  display.clearDisplay();
  int ico_width = 32;
  int ico_height = 32;
  display.drawBitmap(int((DISPLAY_WIDTH - ico_width) / 2), int((DISPLAY_HEIGHT - ico_height) / 2), coffee[count], ico_width, ico_height, WHITE);

  display.display();
  count--;
  if (count < 0)
    count = 27;
}

void fct_wifiLogo()
{
  display.clearDisplay();
  // display count animation image
  int ico_width = 32;
  int ico_height = 32;
  display.drawBitmap(int((DISPLAY_WIDTH - ico_width) / 2), int((DISPLAY_HEIGHT - ico_height) / 2), wifiAnimation[count], ico_width, ico_height, WHITE);
  display.display();
  count--;
  if (count < 0)
    count = 27;
}

float fct_roundToDecimal(double value, int dec)
{
  double mlt = powf(10.0f, dec);
  value = roundf(value * mlt) / mlt;
  return (float)value;
}

void fct_powerDown()
{
  NVS.close();
  digitalWrite(POWERLATCH, LOW);
  digitalWrite(LED, LOW);
}

void fct_powerResetTimer(int t)
{
  powertimer = t;
}

void fct_powerResetTimer()
{
  fct_powerResetTimer(POWERDOWNTIMER);
}

void fct_powerDownTicker()
{
  if(abs(currentScaleValue-lastScaleValue)>MINWEIGHTCHANGETOPREVENTSLEEP){
    fct_powerResetTimer();
  }
  lastScaleValue=currentScaleValue;

  //feed Watchdog
  fct_feedWatchdog();

  powertimer--;
  ESP_LOGV("main", "power down timer %d",powertimer);

  if (powertimer < 1)
  {
    ESP_LOGI("main", "power down");
    fct_powerDown();
  }
}

void fct_timerMode()
{
  start_timer = millis();
  timermode = !timermode;
}

void fct_powerUp()
{
  pinMode(POWERLATCH, OUTPUT);
  digitalWrite(POWERLATCH, HIGH);

  pinMode(LED, OUTPUT);
  digitalWrite(LED, HIGH);

  // ledcAttachPin(LED, 0);
  // ledcSetup(0, 4000, 8);
  // ledcWrite(0, 10);
}

bool inRange(uint32_t val, uint32_t value, double range)
{
  uint32_t minimum = (uint32_t)(value * (1 - range));
  uint32_t maximum = (uint32_t)(value * (1 + range));
  return ((val >= minimum) && (val <= maximum));
}

void fct_initScale()
{
  pinMode(ADC_LDO_EN_PIN, OUTPUT);
  digitalWrite(ADC_LDO_EN_PIN, ADC_LDO_ENABLE);


  const uint8_t DEFAULT_ADC_SPEED = 10; // 10 or 80
  //--------
  scale.begin(0, 128, DEFAULT_ADC_SPEED);
  scale.calibrateADC();

  uint32_t _calFactorULong_ = NVS.getInt("calFactorULong");
  // set CalcFactor only if in a plausible range
  if (inRange(_calFactorULong_, NVS.getInt("validitycheck"), 0.05))
  {
    calFactorULong = _calFactorULong_;
    scale.setCalFactor(calFactorULong / 10000.0);
    ESP_LOGI("main", "setCalFactor: valid");
  }
  else
  {
    ESP_LOGI("main", "setCalFactor: not valid");
  }

//  scale.setSensitivity(120);
//  scale.setSmoothing(5);
  
 scale.setSensitivity(255);
 scale.setSmoothing(1);
 scale.setSpeed(DEFAULT_ADC_SPEED);
}

charging getSOCIdx()
{
  if (soc_battery < 10)
  {
    return BAT_EMPTY;
  }
  else if (soc_battery < 76)
  {
    return BAT_50;
  }
  else if (soc_battery < 101)
  {
    return BAT_100;
  }
  else
  {
    return BAT_EMPTY;
  }
  return BAT_EMPTY;
}

void fct_showText(String text, String text2)
{
  display.clearDisplay();
  display.setTextColor(SSD1306_WHITE);
  display.setFont(&FreeSansBold12pt7b);
  display.setTextSize(1);

  int16_t x = 0;
  int16_t y = 32;
  int16_t x1 = 0;
  int16_t y1 = 0;
  u_int16_t th = 0;
  u_int16_t tw = 0;
  //------------------------
  // for right alignement
  display.getTextBounds(text, x, y, &x1, &y1, &tw, &th);
  display.setCursor(DISPLAY_WIDTH - tw - 10, 20);
  display.println(text);

  if (timermode)
  {
    display.fillRect(0, DISPLAY_HEIGHT / 2, DISPLAY_WIDTH, DISPLAY_HEIGHT, SSD1306_WHITE);
    display.setTextColor(SSD1306_BLACK);
    display.setFont(&FreeSansBold12pt7b);
    display.setTextSize(1);
    display.getTextBounds(text2, x, y, &x1, &y1, &tw, &th);
    display.setCursor(DISPLAY_WIDTH - tw - 10, DISPLAY_HEIGHT - 9);
  }
  else
  {
    display.setFont(&FreeSansBold9pt7b);
    display.setTextSize(1);
    display.setCursor(5, DISPLAY_HEIGHT - 4);
    display.drawBitmap(int((128 - 25)), DISPLAY_HEIGHT - 18, battery[getSOCIdx()], 16, 16, SSD1306_WHITE);
  }
  display.println(text2);
  display.display(); // Show initial text
  display.setTextColor(SSD1306_WHITE);
  delay(100);
}

void fct_calibrationDisplay()
{
  switch (scale.getCalibrationStatus())
  {
  case calibrationStatus::ERROR:
    fct_showText("ERROR!.", "Timeout -> Retry");
    calibrationTimoutTime = 360000;
    break;
  case calibrationStatus::START:
    fct_showText("Calibration", "no weight!");
    break;
  case calibrationStatus::PLACE:
    fct_showText("Calib. 1/4", "place 100g");
    break;
  case calibrationStatus::STAGE_1:
    fct_showText("Calib. 2/4", "");
    break;
  case calibrationStatus::STAGE_2:
    fct_showText("Calib. 3/4", "");
    break;
  case calibrationStatus::STAGE_3:
    fct_showText("Calib. 4/4", "");
    break;
  case calibrationStatus::FINISHED:
    fct_showText("Calib. Done", "Finished");
    break;
  default:
    break;
  }
}

void fct_callCalibrateScale()
{
  do_calibration = true;
}

void fct_calibrateScale()
{
  timermode = false;
  ESP_LOGD("main", "Start Calibration");
  for (int i = 0; i < 20; i++)
  {
    delay(20);
    scale.readUnits(1);
  }
  scale.calibrate(CALIBRATIONWEIGHT, calibrationTimoutTime, 0.05);
  if (scale.getCalibrationStatus() == calibrationStatus::FINISHED)
  {
    calFactorULong = (uint32_t)(scale.getCalFactor() * 10000.0);
    NVS.setInt("calFactorULong", calFactorULong);
    NVS.setInt("validitycheck", calFactorULong);
    ESP_LOGD("main", "Calibration Done:: calFactorULong: %d", calFactorULong);
  }

  for (int i = 0; i < 20; i++)
  {
    delay(100);
  }
  do_calibration = false;
}

// t is time in seconds = millis()/1000;
char *TimeToString(unsigned long t)
{
  static char str[12];

  unsigned long allSeconds = t / 1000;
  unsigned long runMillis = t % 1000;

  sprintf(str, "%d.%03d\'\'", allSeconds, runMillis);
  return str;
}

int once_perSeconde=10;
void fct_mainDisplay()
{
  once_perSeconde--;
  if(once_perSeconde<0){
    fct_powerDownTicker();
    once_perSeconde=10;
  }

  // wenn calibration
  if (do_calibration)
  {
    fct_calibrationDisplay();
    return;
  }

  // if update active
  if (activeWifi && Update.isRunning())
  {
    double prog = Update.progress() / Update.size();
    fct_showText("FW upgr.", ":: => " + String(prog) + "%");
    return;
  }

  //if timermode
  if (timermode)
  {
    fct_showText(String(fct_roundToDecimal(currentScaleValue, 2)) + " g", String(TimeToString(millis() - start_timer)));
    return;
  }

  //if scale only
  if (!timermode)
  {
    fct_showText(String(fct_roundToDecimal(currentScaleValue, 2)) + " g", "Bat: " + String(soc_battery) + "%");
    return;
  }
  return;
}

void fct_setupDisplay()
{
  Wire.begin(DISPLAY_MOSI_PIN, DISPLAY_CLK_PIN);
  ESP_LOGV("main", "Wire Init");
  if (!display.begin(SSD1306_SWITCHCAPVCC, 0x3C))
  {
    ESP_LOGE("main", "SSD1306 allocation failed");
  }
  display.display();
  display.setRotation(2);
  display.clearDisplay();
}

void fct_setWifi()
{

  ESP_LOGV("main", "activeWifi to: %d", activeWifi);
  if (activeWifi)
  {
    displayTicker.detach();
    displayTicker.attach_ms(40, fct_wifiLogo);
    WiFi.mode(WIFI_STA);
    WiFi.begin(SSID, PASSWORD);

    // Wait for connection
    while (WiFi.status() != WL_CONNECTED)
    {
      delay(500);
      ESP_LOGV("main", "Wait for connection");
    }

    ESP_LOGI("main", "Setup UDP to Server: %s & PORT: %d", UDP_SERVER_IP, UDP_SERVER_PORT);

    IPAddress udpIP;
    udpIP.fromString(UDP_SERVER_IP);
    udp_logging_init(udpIP, UDP_SERVER_PORT, udp_logging_vprintf);

    ESP_LOGV("main", "Connected to: %s", SSID);
    ESP_LOGV("main", "IP address:  %s", WiFi.localIP().toString().c_str());

    server.on("/", HTTP_GET, [](AsyncWebServerRequest *request)
              { request->send(200, "text/plain", "Hi! I am a Scale."); });

    AsyncElegantOTA.begin(&server); // Start ElegantOTA
    server.begin();
    ESP_LOGV("main", "HTTP server started");
    displayTicker.detach();
  }
}

void setup()
{
  fct_powerUp();
  Serial.begin(115200);
  fct_setupWatchdog();
  fct_feedWatchdog();

  fct_setupDisplay();
#ifdef WIFIDEBUG // if WiFi is enabled by default start it. otherwise after scale if requested. Good for debugging
  esp_log_level_set("*", CORE_DEBUG_LEVEL);
#endif
  ESP_LOGV("main", "Setup: fct_setupDisplay");
//---------------------
#ifdef WIFIDEBUG // if WiFi is enabled by default start it. otherwise after scale if requested. Good for debugging
  fct_setWifi();
#endif
  //---------------------
  displayTicker.attach_ms(40, fct_bootLogo);
  button_setup();
  fct_powerResetTimer();
  activeWifi = (activeWifi || wifiActivationRequested());

  // ---------------------
  NVS.begin();
  // ---------------------
  fct_feedWatchdog();
  fct_initScale();
  ESP_LOGV("main", "Setup: fct_initScale");
  //---------------------

  scale.tare(2, false, true, true);
  ESP_LOGV("main", "Setup: scale.tare");
  activeWifi = (activeWifi || wifiActivationRequested());

  //---------------------
  for (int i = 0; i < 3; i++)
  {
    soc_battery = monitoring.getSOC();
    delay(30);
  }
  fct_feedWatchdog();
  //---------------------
  displayTicker.detach();
//---------------------
#ifndef WIFIDEBUG
  fct_setWifi();
#endif
  //---------------------
  //main display Ticker function
  displayTicker.attach_ms(100, fct_mainDisplay);
}

uint32_t u_time = 0;
uint32_t lastVinRead = 0;

void loop()
{
  //---- Button  Loop
  button_loop();

  //---- Scale  Loop
  if ((millis() - u_time >= 30))
  {
    currentScaleValue=scale.readUnits(1);
    u_time = millis();
  }

  //---- Battery Loop
  if (millis() - lastVinRead >= (batReadInterval * 1000))
  {
    soc_battery = monitoring.getSOC();
    lastVinRead = millis();
  }


  //---- Call Calibration if requested
  if (do_calibration)
  {
    timerAlarmDisable(wdtTimer);   
    fct_calibrateScale();
    timerAlarmEnable(wdtTimer);
  }

}

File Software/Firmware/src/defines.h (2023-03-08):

#define ADC_LDO_EN_PIN 21
#define ADC_LDO_ENABLE 1 //high or low for enable ??? Check datasheet of your LDO.
#define ADC_LDO_DISABLE 0 //high or low for disable ??? Check datasheet of your LDO.



  
#define ADC_PDWN_PIN 5
#define ADC_DOUT_PIN 19
#define ADC_SCLK_PIN 18
#define ADC_GAIN0_PIN 16
#define ADC_GAIN1_PIN 17
#define ADC_SPEED_PIN 22

#define ADC_A0_PIN 0 //tied to GND AIN1 in orginal PCB -> 0 means disable the Channel select
// #define ADC_A0_PIN 27 //in my one tied to GPIO 27 to enable dual scale
#define ADC_TEMP_PIN 0 //tied to GND AIN1 in PRO

#define DISPLAY_WIDTH 128 // display width, in pixels
#define DISPLAY_HEIGHT 64
#define DISPLAY_MOSI_PIN 13 //SDA if using I2C
#define DISPLAY_CLK_PIN 14 //SCL is using I2C

#define INITIALISING_SECS 5 //high or low for enable ??? Check datasheet of your LDO.

#define  POWER_BUTTON_PIN 33
#define  TARE_BUTTON_PIN 32
#define  SECONDARY1_BUTTON_PIN  12



// #define POWERLATCH 35
#define POWERLATCH 4
#define LED 2
#define POWERDOWNTIMER 60*2


#define WATCHDOGTIMEOUT 16 //secondes


uint8_t batReadInterval = 10; //in seconds - defines how frequently we should read the voltage from our voltage divider.
int soc_battery=0;
#define CALIBRATIONWEIGHT 100 //Calibration weight in gramm
// #define CALFACTORDEFAULT 424066   //for my MARVIN NA1 better default  7101991
#define CALFACTORDEFAULT 7101991   //for my MARVIN NA1 better default  7101991

//UDP SETTINGS
#define UDP_SERVER_IP "192.168.178.100" // UDP LOG Server
#define UDP_SERVER_PORT 44444           // UDP Port Server

#define MINWEIGHTCHANGETOPREVENTSLEEP 2
// ----------------------
// 
//  !!!!!!!!!!!!!!!!!!!!!!!!!!!!!!!!!!!!!!
// Further Scale Tweaking in scale.h
// 
// ----------------------



const unsigned char waitLogo[28] [128] PROGMEM = {

	// 'frame_00_delay-0, 32x32px

{	0x00, 0x00, 0x00, 0x00, 0x00, 0x00, 0x00, 0x00, 0x00, 0x00, 0x00, 0x00, 0x00, 0x00, 0x00, 0x00, 
	0x00, 0x00, 0x00, 0x00, 0x00, 0x00, 0x00, 0x00, 0x00, 0x00, 0x00, 0x00, 0x00, 0x00, 0x00, 0x00, 
	0x00, 0x00, 0x00, 0x00, 0x00, 0x00, 0x00, 0x00, 0x00, 0x00, 0x00, 0x00, 0x00, 0x00, 0x00, 0x00, 
	0x00, 0x00, 0x00, 0x00, 0x00, 0x03, 0xc0, 0x00, 0x0c, 0x07, 0xe0, 0x70, 0x0e, 0x07, 0xe0, 0x78, 
	0x0e, 0x07, 0xe0, 0x78, 0x0c, 0x07, 0xe0, 0x70, 0x00, 0x03, 0xc0, 0x00, 0x00, 0x00, 0x00, 0x00, 
	0x00, 0x00, 0x00, 0x00, 0x00, 0x00, 0x00, 0x00, 0x00, 0x00, 0x00, 0x00, 0x00, 0x00, 0x00, 0x00, 
	0x00, 0x00, 0x00, 0x00, 0x00, 0x00, 0x00, 0x00, 0x00, 0x00, 0x00, 0x00, 0x00, 0x00, 0x00, 0x00, 
	0x00, 0x00, 0x00, 0x00, 0x00, 0x00, 0x00, 0x00, 0x00, 0x00, 0x00, 0x00, 0x00, 0x00, 0x00, 0x00
}, 
	// 'frame_01_delay-0, 32x32px

{	0x00, 0x00, 0x00, 0x00, 0x00, 0x00, 0x00, 0x00, 0x00, 0x00, 0x00, 0x00, 0x00, 0x00, 0x00, 0x00, 
	0x00, 0x00, 0x00, 0x00, 0x00, 0x00, 0x00, 0x00, 0x00, 0x00, 0x00, 0x00, 0x00, 0x00, 0x00, 0x00, 
	0x00, 0x00, 0x00, 0x00, 0x00, 0x00, 0x00, 0x00, 0x00, 0x00, 0x00, 0x00, 0x00, 0x00, 0x00, 0x00, 
	0x00, 0x00, 0x00, 0x00, 0x00, 0x03, 0xc0, 0x00, 0x04, 0x07, 0xe0, 0x78, 0x0e, 0x07, 0xe0, 0xf8, 
	0x0e, 0x07, 0xe0, 0xf8, 0x04, 0x07, 0xe0, 0x78, 0x00, 0x03, 0xc0, 0x00, 0x00, 0x00, 0x00, 0x00, 
	0x00, 0x00, 0x00, 0x00, 0x00, 0x00, 0x00, 0x00, 0x00, 0x00, 0x00, 0x00, 0x00, 0x00, 0x00, 0x00, 
	0x00, 0x00, 0x00, 0x00, 0x00, 0x00, 0x00, 0x00, 0x00, 0x00, 0x00, 0x00, 0x00, 0x00, 0x00, 0x00, 
	0x00, 0x00, 0x00, 0x00, 0x00, 0x00, 0x00, 0x00, 0x00, 0x00, 0x00, 0x00, 0x00, 0x00, 0x00, 0x00
}, 
	// 'frame_02_delay-0, 32x32px

{	0x00, 0x00, 0x00, 0x00, 0x00, 0x00, 0x00, 0x00, 0x00, 0x00, 0x00, 0x00, 0x00, 0x00, 0x00, 0x00, 
	0x00, 0x00, 0x00, 0x00, 0x00, 0x00, 0x00, 0x00, 0x00, 0x00, 0x00, 0x00, 0x00, 0x00, 0x00, 0x00, 
	0x00, 0x00, 0x00, 0x00, 0x00, 0x00, 0x00, 0x00, 0x00, 0x00, 0x00, 0x00, 0x00, 0x00, 0x00, 0x00, 
	0x00, 0x00, 0x00, 0x00, 0x00, 0x03, 0xc0, 0x20, 0x00, 0x07, 0xe0, 0x78, 0x0e, 0x07, 0xe0, 0xf8, 
	0x0e, 0x07, 0xe0, 0xf8, 0x00, 0x07, 0xe0, 0x78, 0x00, 0x03, 0xc0, 0x30, 0x00, 0x00, 0x00, 0x00, 
	0x00, 0x00, 0x00, 0x00, 0x00, 0x00, 0x00, 0x00, 0x00, 0x00, 0x00, 0x00, 0x00, 0x00, 0x00, 0x00, 
	0x00, 0x00, 0x00, 0x00, 0x00, 0x00, 0x00, 0x00, 0x00, 0x00, 0x00, 0x00, 0x00, 0x00, 0x00, 0x00, 
	0x00, 0x00, 0x00, 0x00, 0x00, 0x00, 0x00, 0x00, 0x00, 0x00, 0x00, 0x00, 0x00, 0x00, 0x00, 0x00
}, 
	// 'frame_03_delay-0, 32x32px
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

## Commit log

2022-11-02 remove timer
2022-11-03 BootLogo, BatteryIcon
2022-11-04 Timer & Display
2022-11-04 HW Update
    [LunarEclipse_BOM_v4.xlsx, LunarEclipse_PinoutReference_v4.xlsx, PRO_BOM_v2.xlsx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]
2022-11-05 Calibration Display
2022-11-05 remove original
    [ESPresso_Scale_v33.f3d]
2022-11-05 case tweaks
    [ESPressoScale.f3d]
2022-11-06 auto powerdown & scaleingFactor fix
    [defines.h, main.cpp, scale.h]
2022-11-12 NVS reset and trigger calibration
    [scale.h]
2022-11-20 if calibration fails don not store value
    [main.cpp]
2022-11-21 format fixes and FW display
    [main.cpp]
2022-11-22 Marvin NA1 case draft
    [ESPressoScale_Mavin_NA1.f3d]
2022-12-14 HW Change
    [DualEspressobom.xls, PickAndPlace_ESPressoScaleProDual_2022-11-28.csv]
2022-12-18 PCB JLPCB Order
    [JLPCB_BOM.xls, JLPCB_PickAndPlace.csv, PickAndPlace_ESPressoScaleProDual_2022-11-28.csv]
2022-12-18 Schematics &easyeda Update
2022-12-18 PCB Assembly Guide
2022-12-18 HW Documentation
    [BOM_ESPressoScale Pro_2022-11-04.csv, BOM_Help.xlsx]
2022-12-29 case fixes
    [ESPressoScale.f3d, ESPressoScale_Mavin_NA27.f3d]
2023-01-05 bom update
    [JLPCB_BOM.xls]
2023-01-19 BOM Fix (wrong F1-F7)
    [JLPCB_BOM.xls]
2023-01-25 PCB Update
    [JLPCB_BOM.xls, JLPCB_BOM_Pro.xls, JLPCB_PickAndPlace_Pro.csv]
2023-03-08 watchdog and other little tweaks
    [JLPCB_BOM_Pro.xls]
